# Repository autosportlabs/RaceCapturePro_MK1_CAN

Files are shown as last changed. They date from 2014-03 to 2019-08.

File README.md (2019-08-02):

CAN for RaceCapture/Pro MK1
====

CAN Bus interface module for RaceCapture/Pro MK1 only. This adds a single CAN bus interface channel that integrates with the SPI interface available on RJ45 port. 

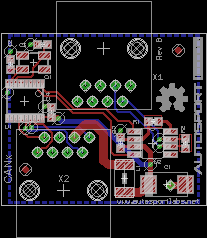
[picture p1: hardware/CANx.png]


See the LICENSE.txt for information on the technology license

Autosport Labs
http://www.autosportlabs.com

Building the CANx board
=======================

Parts are defined in the CANx.csv. 

* All resistors are 0603 5%
* All capacitors are 0603 X7R

Connecting CANx
===============

Connect a short (6" or shorter) RJ45 cable with pins wired straight through between RaceCapture/Pro MK1 and the X2 port of CANx. A simple ethernet 6" extension cable should work fine. 

The CAN bus connection is available on X1 and conforms to the same pinout as RaceCapture/Pro MK2. And, you can use the same CAN->OBDII cable used on the newer versions of RaceCapture/Pro.

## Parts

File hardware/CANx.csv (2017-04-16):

Qty | Value | Device | Package | Parts | Description
1 |  | MCP2515ST | TSSOP20 | U1 | MC2515
1 |  | WE-CBF_1812 | 1812 | L1 | SMD EMI Suppression Ferrite Beads
1 | 0.1uF | C-USC0603K | C0603K | C4 | CAPACITOR, American symbol
1 | 0.1uf | C-USC0603K | C0603K | C5 | CAPACITOR, American symbol
1 | 10uF | CPOL-USSMCD | SMC_D | C1 | POLARIZED CAPACITOR, American symbol
1 | 120 | R-US_R0603 | R0603 | R2 | RESISTOR, American symbol
1 | 16MHz | CRYSTAL5X3 | CRYSTAL-SMD-5X3 | Q1 | Crystals
2 | 22pF | C-USC0603K | C0603K | C2, C3 | CAPACITOR, American symbol
1 | 4.7K | R-US_R0603 | R0603 | R1 | RESISTOR, American symbol
1 | MCP2551SO8 | MCP2551SO8 | SO08 | U2 | CAN Tranceiver Microchip
2 | RJ45_RIGHT_ANGLEMOLEX_95001-2881 | RJ45_RIGHT_ANGLEMOLEX_95001-2881 | RJ45_RIGHT_ANGLE_MOLEX_95001-2881 | X1, X2

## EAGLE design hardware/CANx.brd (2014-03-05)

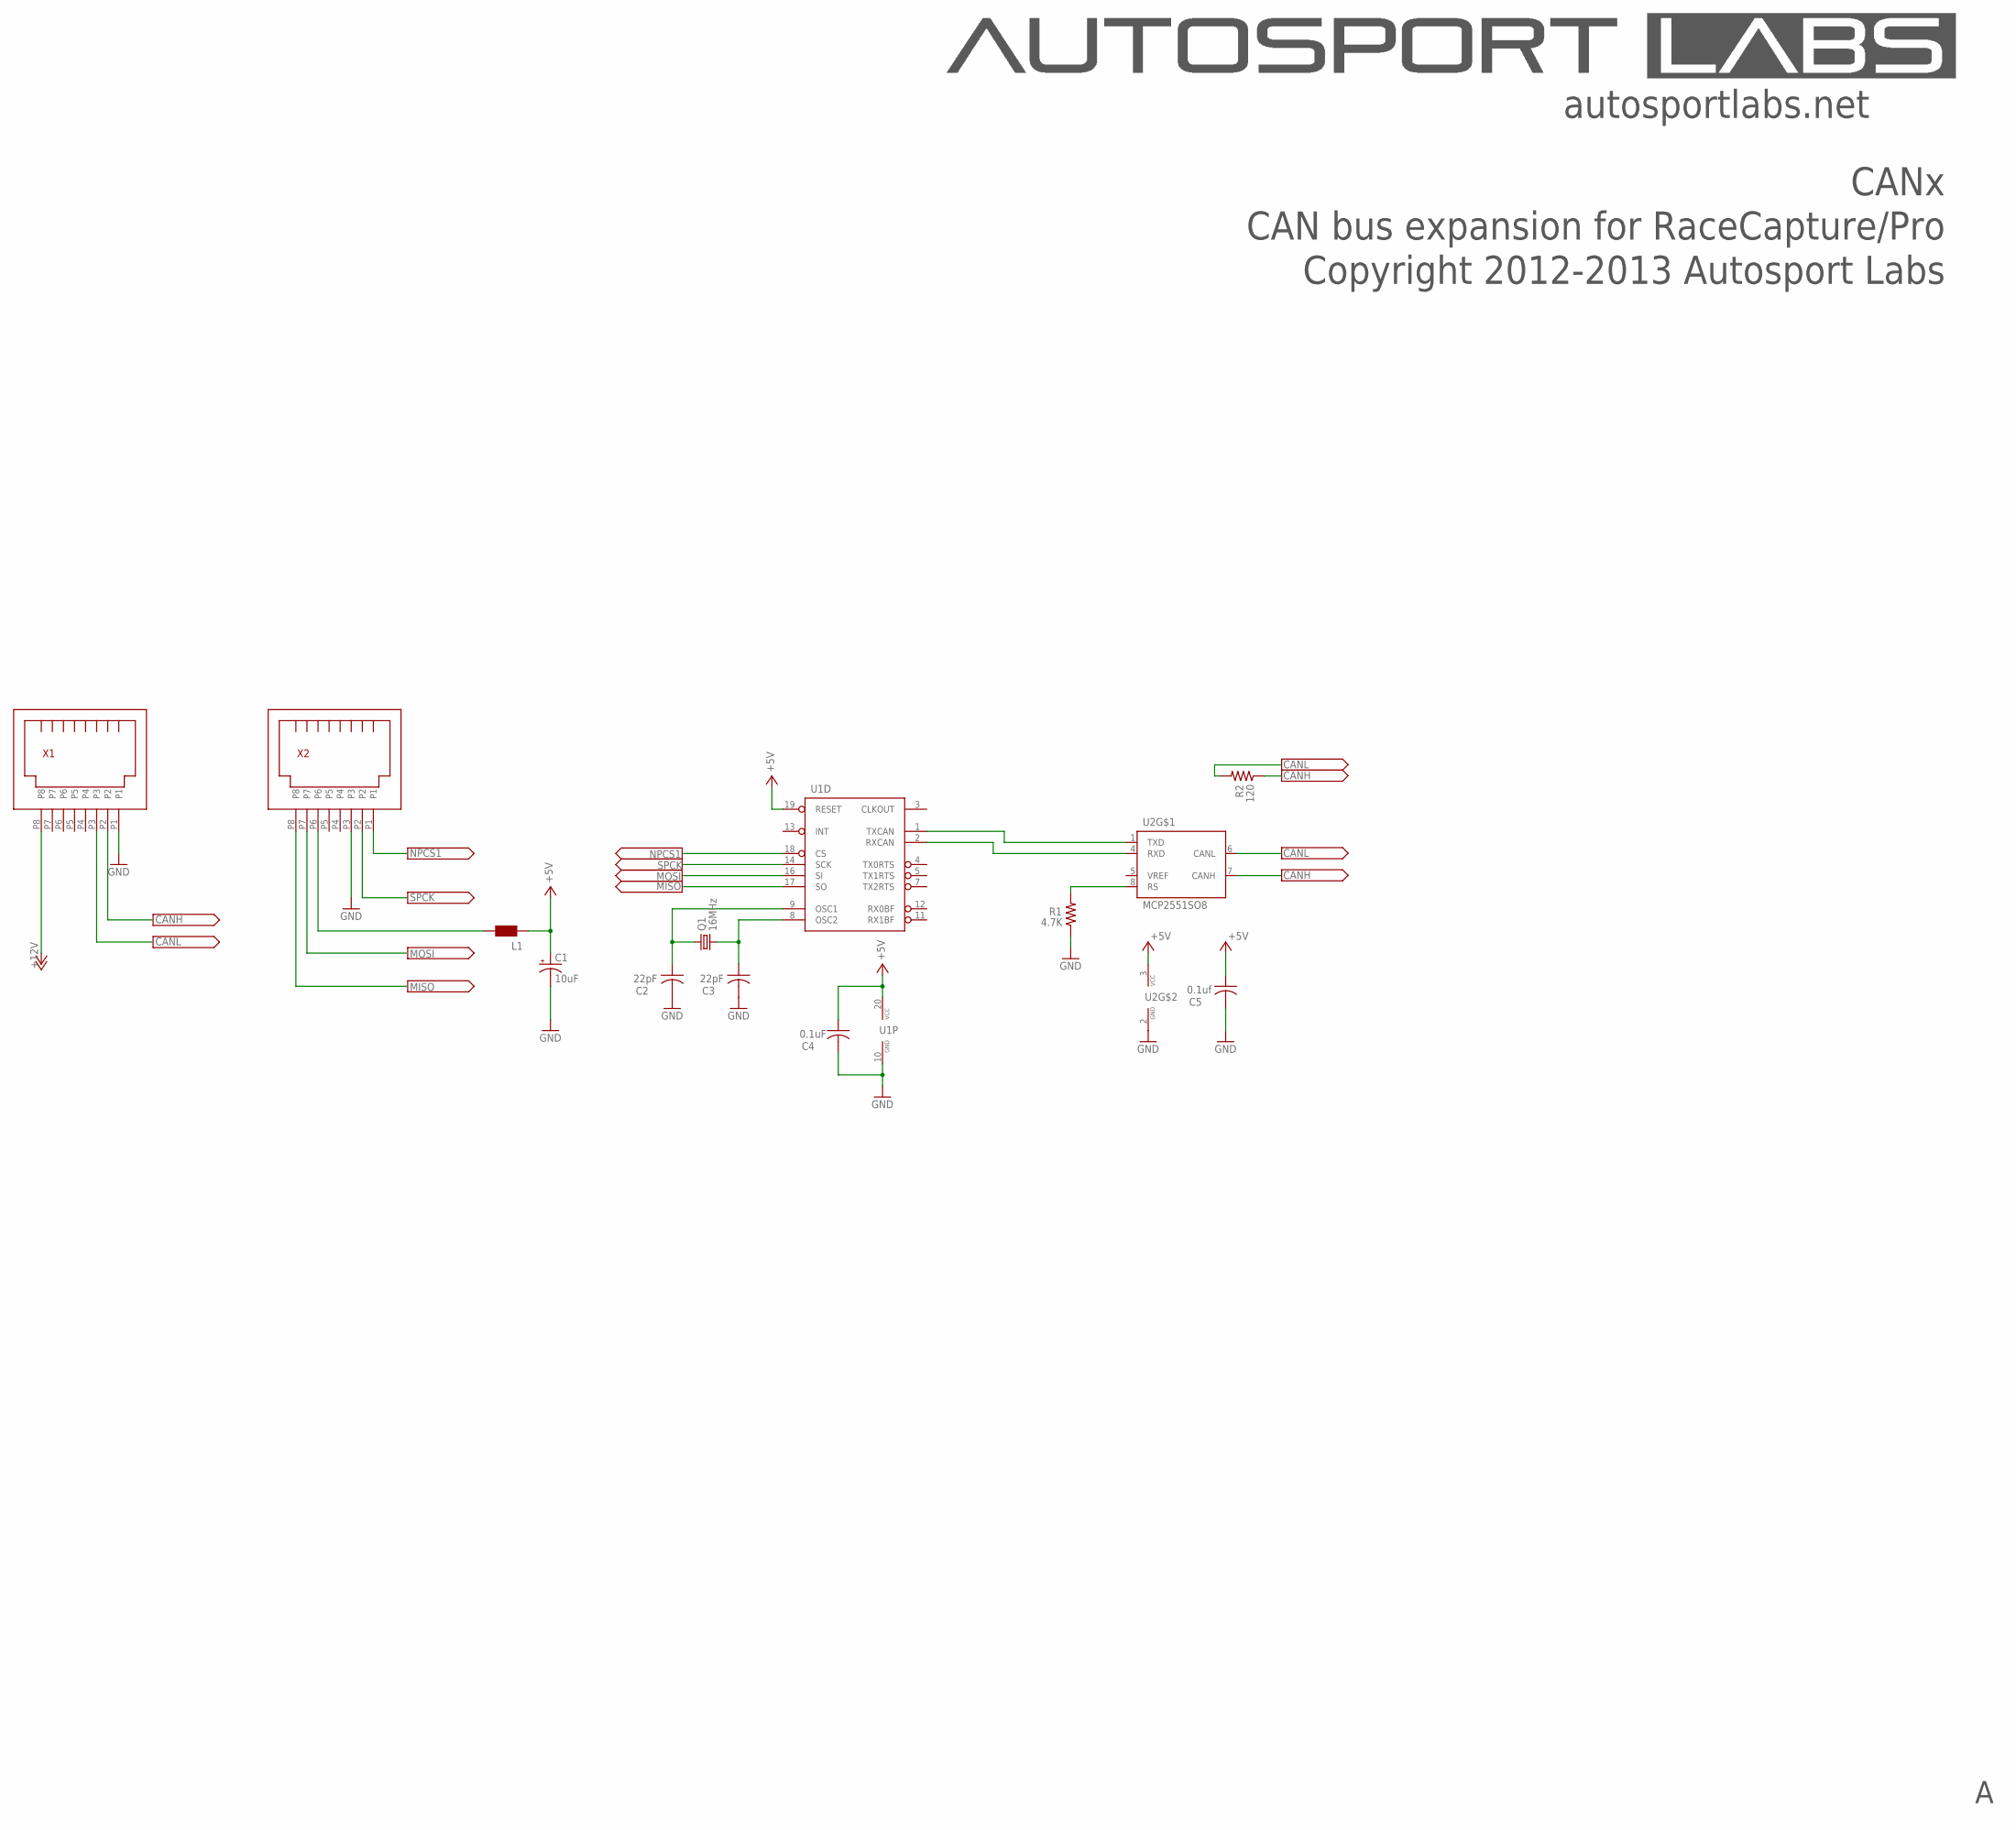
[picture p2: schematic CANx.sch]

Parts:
C1: 10uF; SMC_D
C2, C3: 22pF; C0603K
C4: 0.1uF; C0603K
C5: 0.1uf; C0603K
L1: WE-CBF_1812; 1812
Q1: 16MHz; CRYSTAL-SMD-5X3
R1: 4.7K; R0603
R2: 120; R0603
U1: MCP2515ST; TSSOP20
U2: MCP2551SO8; SO08
X1, X2: RJ45_RIGHT_ANGLEMOLEX_95001-2881; RJ45_RIGHT_ANGLE_MOLEX_95001-2881

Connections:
+5V: C1.+, C4.1, C5.1, L1.1, U1.19 (RESET), U1.20 (VCC), U2.3 (VCC)
+12V: X1.P8
CAN1_RX: U1.2 (RXCAN), U2.4 (RXD)
CAN1_TX: U1.1 (TXCAN), U2.1 (TXD)
CANH: R2.1, U2.7 (CANH), X1.P2
CANL: R2.2, U2.6 (CANL), X1.P3
GND: C1.-, C2.2, C3.2, C4.2, C5.2, R1.1, U1.10 (GND), U2.2 (GND), X1.P1, X2.P3
MISO: U1.17 (SO), X2.P8
MOSI: U1.16 (SI), X2.P7
unnamed: C2.1, Q1.3 (2), U1.9 (OSC1)
unnamed: C3.1, Q1.1, U1.8 (OSC2)
unnamed: L1.2, X2.P6
unnamed: R1.2, U2.8 (RS)
NPCS1: U1.18 (CS), X2.P1
SPCK: U1.14 (SCK), X2.P2

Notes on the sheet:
Copyright 2012-2013 Autosport Labs
CANx
autosportlabs.net
CAN bus expansion for RaceCapture/Pro

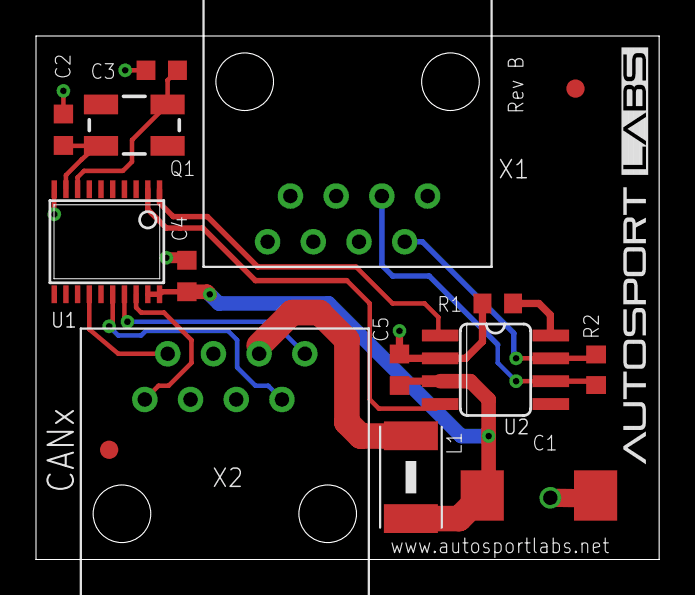
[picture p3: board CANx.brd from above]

Board: 2 copper layers, 34.6 x 29.1 mm, 13 parts (0 on the bottom side), 14 nets.

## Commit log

2013-10-30 added initial files
    [CANx.brd, CANx.sch]
2013-10-30 shrunk design of design to fit same enclosure as BT module
    [CANx.brd, CANx.sch]
2013-10-30 fixed airwires
    [CANx.brd, CANx.sch]
2013-10-30 added board image
2014-03-05 updated CANx to use TSSOP-20 and center CAN connection plug to make it easier to identify orientation
    [CANx.brd, CANx.sch]
2017-04-10 added BOM, updated readme
2017-04-16 add BOM
    [CANx.csv]
